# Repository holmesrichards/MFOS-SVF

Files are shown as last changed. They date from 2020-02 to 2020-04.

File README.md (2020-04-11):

# MFOS-SVF
Eurorack adaptation of the MFOS "Oldie But Goody" state variable filter

This is a Eurorack version of a state variable voltage controlled filter by Ray Wilson of musicfromouterspace.com. At that site there is a state variable VCF listed under "Analog Synthesizer Modules" but this project is based on another, earlier design listed under "Oldies But Goodies" at http://musicfromouterspace.com/index.php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.

Wilson's design was for a module in his own preferred format, with ±12V and ground soldered to the board and panel hardware mounted to the panel and wired to the board. This version has a Eurorack power connector and has panel hardware mounted to a panel PCB coupled to a main PCB with most of the circuitry.

Included in this repository are KiCad-format schematics and PCB designs for the two circuit boards, as well as an Inkscape .svg file for the panel design and a KiCad-format "PCB" for fabrication of the panel by a PCB company.

The schematics are closely based upon Wilson's original and are governed by licensing information at http://musicfromouterspace.com. The PCB layouts and panel design are new, by Richard Holmes.

BOMs are here:
https://github.com/holmesrichards/MFOS-SVF/blob/master/OBG-SVF-mainPCB/OBG-SVF-mainpcb_bom.md
and here:
https://github.com/holmesrichards/MFOS-SVF/blob/master/OBG-SVF-panelPCB/OBG-SVF-panelpcb_bom.md

## Build notes

Pretty standard. Panel PCB and main PCB joined with 2x6 pin header/socket. Use two 10 mm M3 spacers and four M3 screws to hold them together.

This time most of the components go on the panel-facing side. The power header and trimmer go on the other side. I intended the electrolytics to go on the panel-facing side but mine were too tall to fit between the boards so I mounted them on the other side.

The trimmer adjusts V/Oct response. Adjust it so a change of 1 octave (1V) on the CV input results in a change of 18 mV at the base of Q1.

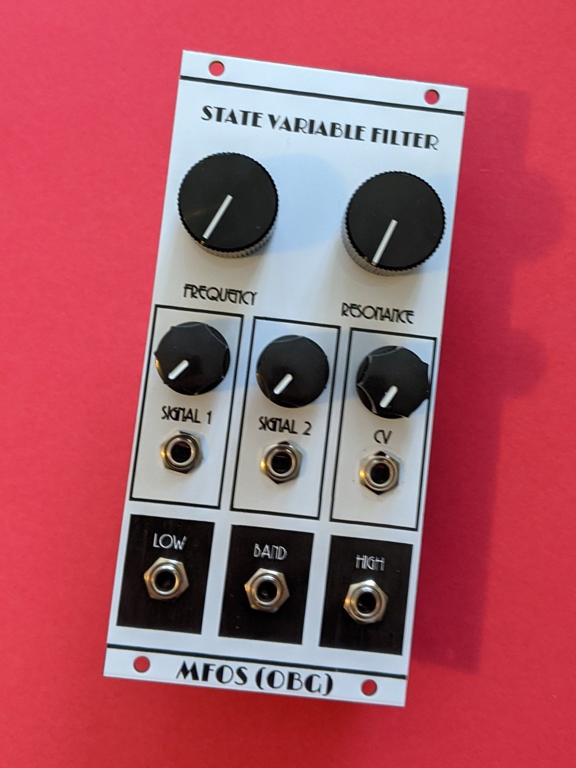
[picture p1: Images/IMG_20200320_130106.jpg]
module pic


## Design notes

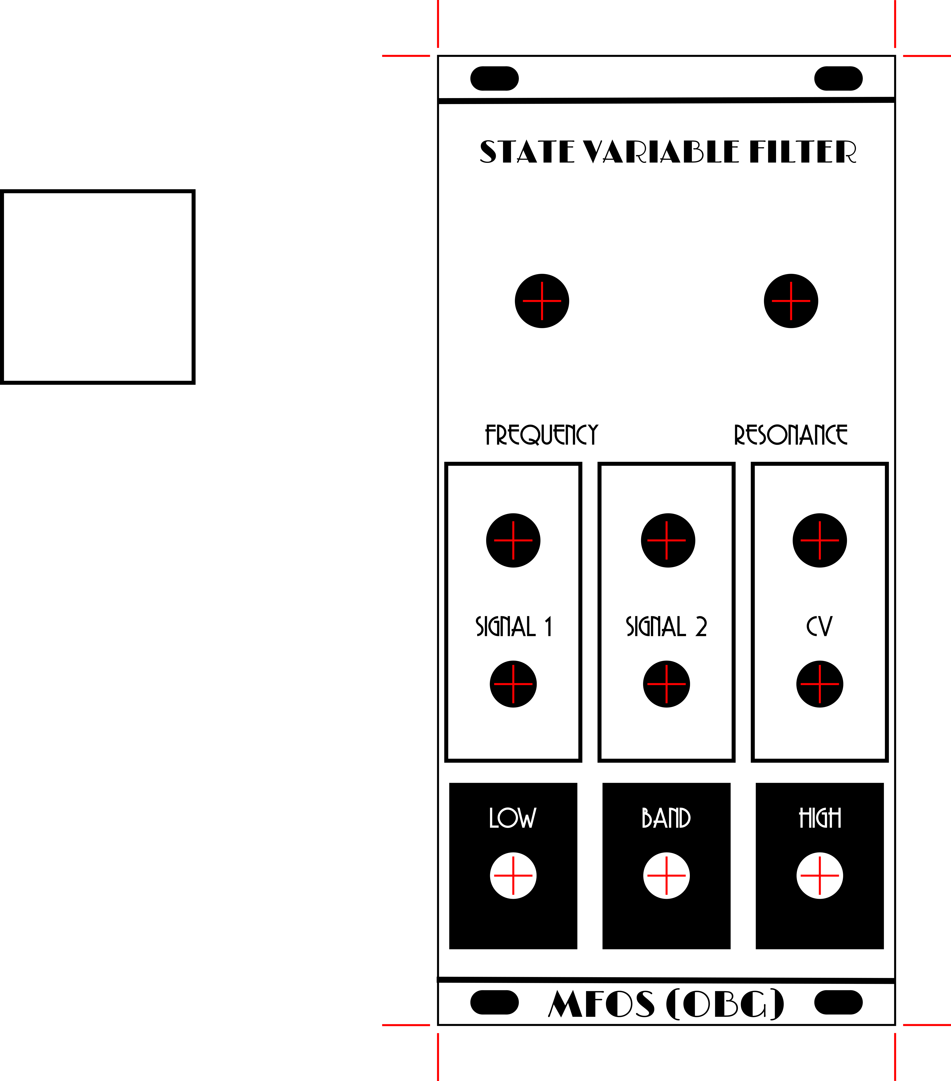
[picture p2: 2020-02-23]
OBG-SVF-panel/art labels holes.png

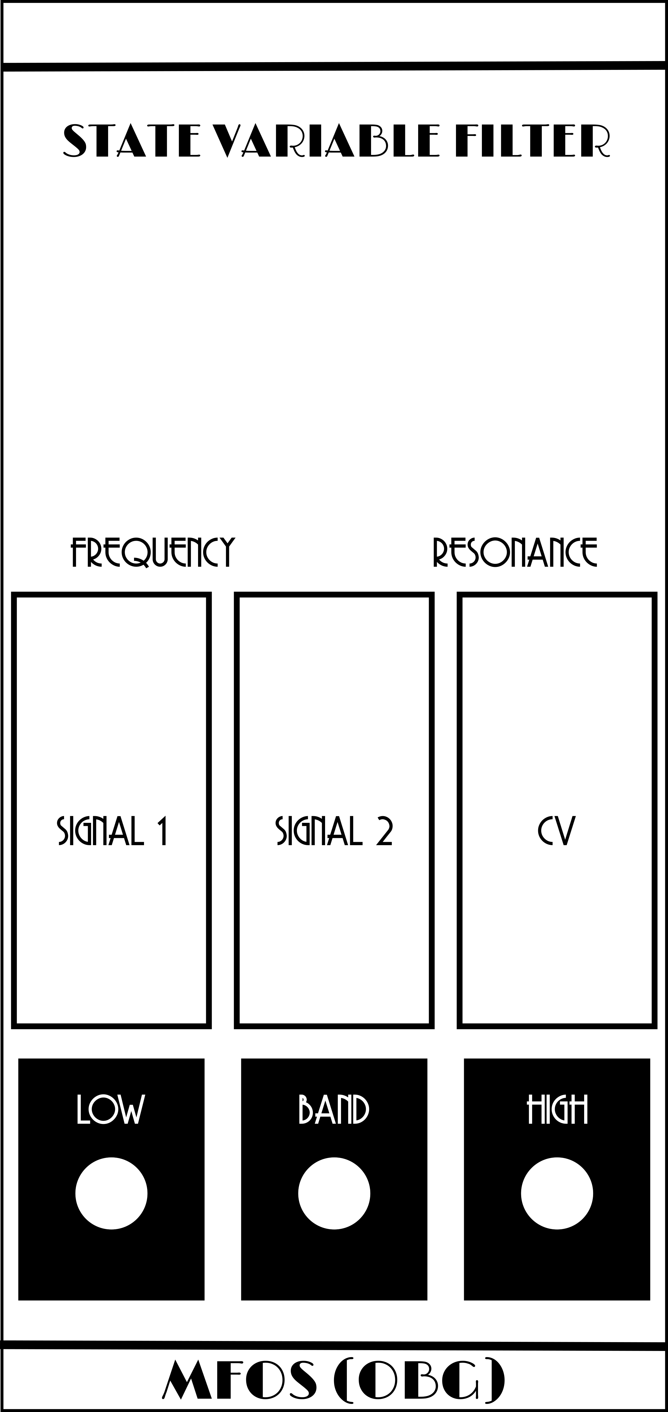
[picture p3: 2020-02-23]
OBG-SVF-panel/art labels.png

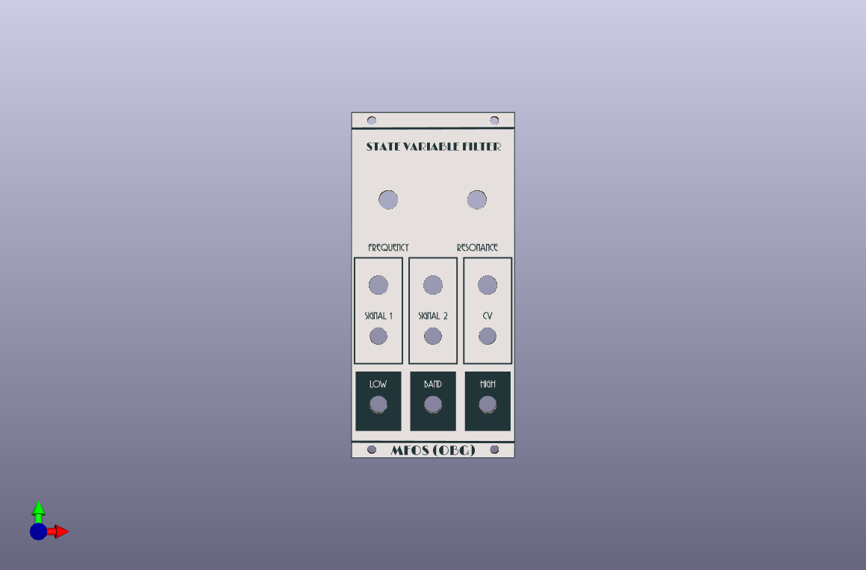
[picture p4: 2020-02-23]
OBG-SVF-panel/obg-SVF-panel.png

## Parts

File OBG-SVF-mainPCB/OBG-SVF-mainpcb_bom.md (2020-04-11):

# OBG-SVF-mainpcb BOM

Sat 11 Apr 2020 01:31:15 PM EDT

Generated from schematic by Eeschema 5.1.5-52549c5~84~ubuntu18.04.1

**Component Count:** 36

| Value | Qty | Part | Description | Vendor |
| ----- | --- | ---- | --- | --- |
| C1, C2 | 2 | 470pF | Unpolarized capacitor |  |
| C3, C4 | 2 | 10U | Polarized capacitor |  |
| C5, C6, C7, C8 | 4 | 0.1uF | Unpolarized capacitor |  |
| D1, D2 | 2 | 1N5817 | 20V 1A Schottky Barrier Rectifier Diode, DO-41 |  |
| J7 | 1 | EURO_PWR_2x5 | Eurorack style 2x5 pin power header |  |
| J8 | 1 | Conn_02x06_Odd_Even | Generic connector, double row, 02x06 |  |
| Q1 | 1 | 2N3904 | 0.2A Ic, 40V Vce, Small Signal NPN Transistor, TO-92 |  |
| Q2, Q3 | 2 | 2N3906 | -0.2A Ic, -40V Vce, Small Signal PNP Transistor, TO-92 |  |
| R3, R12 | 2 | 2k | Resistor |  |
| R4, R10, R15 | 3 | 47k | Resistor |  |
| R7 | 1 | 100R | Trim-potentiometer |  |
| R11, R17, R20 | 3 | 100k | Resistor |  |
| R13 | 1 | 470R | Resistor |  |
| R14 | 1 | 120k | Resistor |  |
| R18, R19 | 2 | 20k | Resistor |  |
| R21, R22 | 2 | 1k | Resistor |  |
| R25, R27 | 2 | 39k | Resistor |  |
| R26, R28 | 2 | 150k | Resistor |  |
| U1 | 1 | TL084 | Quad JFET-Input Operational Amplifiers, DIP-14 |  |
| U2 | 1 | LM13700 | Dual Operational Transconductance Amplifiers with Linearizing Diodes and Buffers, DIP-16 |  |

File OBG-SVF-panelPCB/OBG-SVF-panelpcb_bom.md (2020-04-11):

# OBG-SVF-panelpcb BOM

Sat 11 Apr 2020 01:33:45 PM EDT

Generated from schematic by Eeschema 5.1.5-52549c5~84~ubuntu18.04.1

**Component Count:** 20

| Value | Qty | Part | Description | Vendor |
| ----- | --- | ---- | --- | --- |
| J1, J2, J3, J4, J5, J6 | 6 | AudioJack2 |  |  |
| J9 | 1 | Conn_02x06_Odd_Even | Generic connector, double row, 02x06, odd/even pin numbering scheme (row 1 odd numbers, row 2 even numbers), script generated (kicad-library-utils/schlib/autogen/connector/) |  |
| R1, R5, R31, R32, R33 | 5 | 100k | Potentiometer |  |
| R2, R6 | 2 | 100k | Resistor |  |
| R8 | 1 | 9.1k | Resistor |  |
| R9, R29 | 2 | 270k | Resistor |  |
| R16, R23, R24 | 3 | 1k | Resistor |  |
    
*Additional parts not on schematic:*

| Qty | Part | Description |
| --- | ---- | --- |
| 2 | 10 mm x M3 | Spacer |
| 4 | M3 | Screw |
| 5 | | Knob |

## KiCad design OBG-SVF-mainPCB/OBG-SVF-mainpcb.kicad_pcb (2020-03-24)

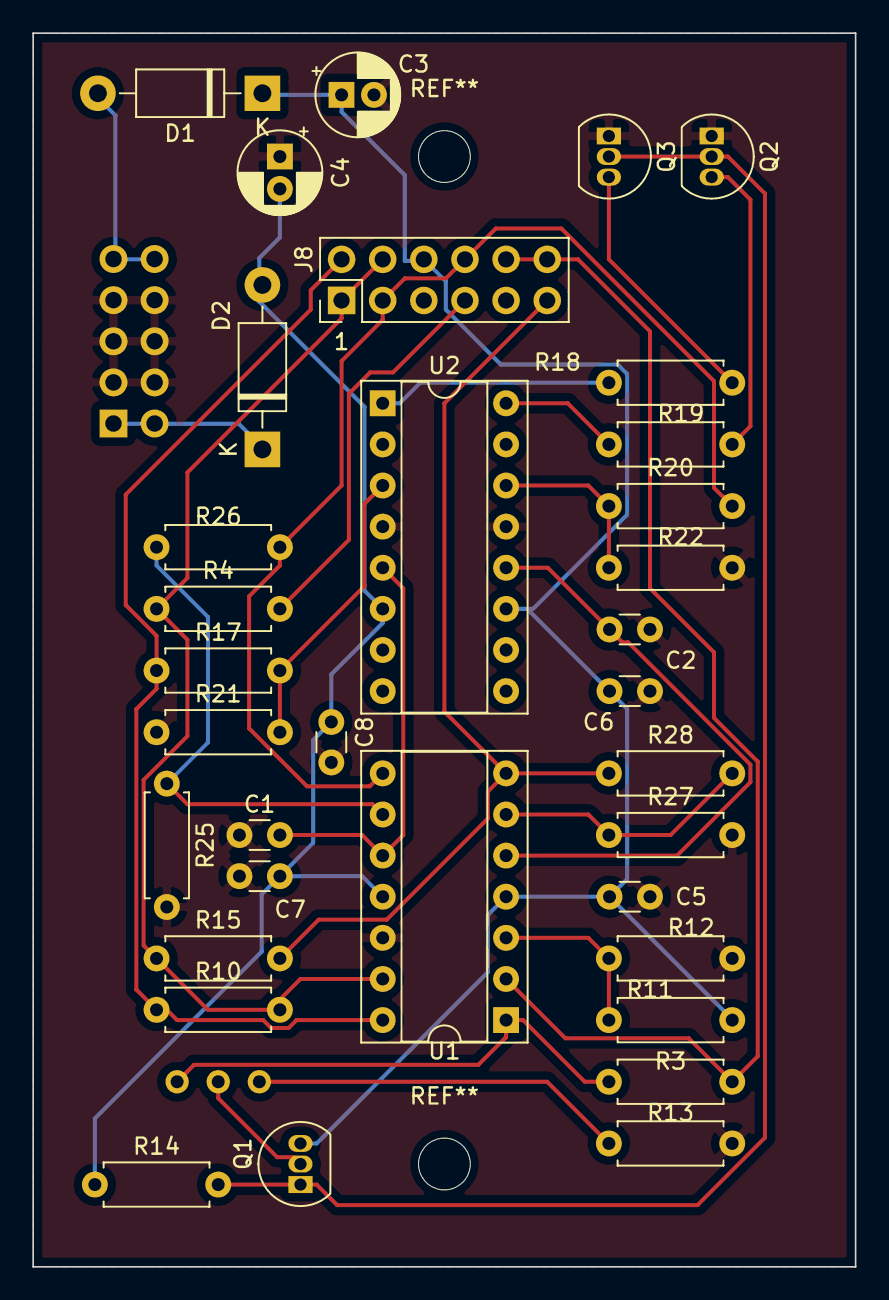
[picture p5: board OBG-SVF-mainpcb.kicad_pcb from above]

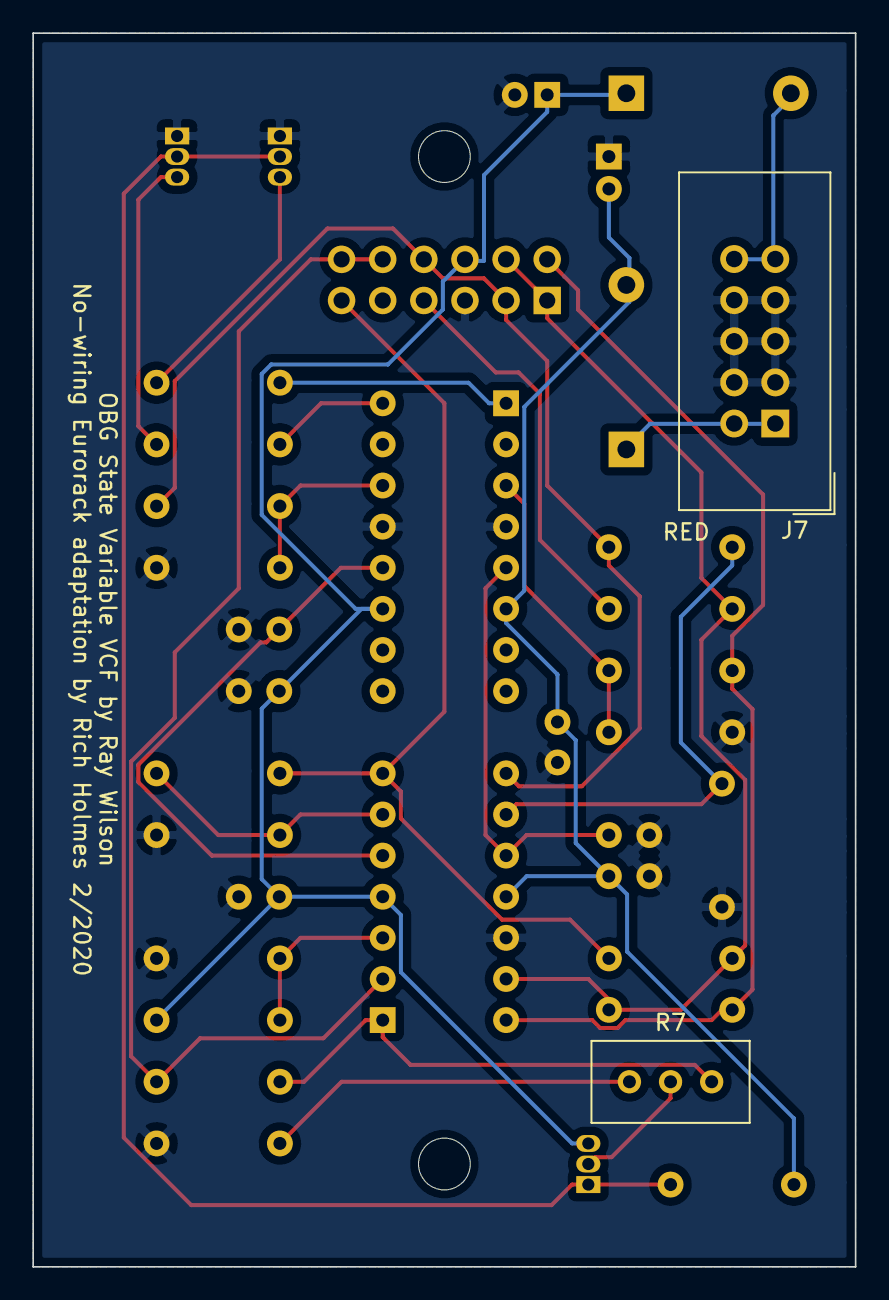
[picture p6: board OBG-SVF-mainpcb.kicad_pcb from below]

Board: 2 copper layers, 50.8 x 76.2 mm, 36 parts (2 on the bottom side), 26 nets.

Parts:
C1, C2: 470pF; C_Disc_D3.0mm_W1.6mm_P2.50mm
C3, C4: 10U; CP_Radial_D5.0mm_P2.00mm
C5, C6, C7, C8: 0.01U; C_Disc_D3.0mm_W1.6mm_P2.50mm
D1, D2: 1N5817; D_DO-41_SOD81_P10.16mm_Horizontal
J7: EURO_PWR_2x5; Eurorack_Power_Header_Shrouded
J8: Conn_02x06_Odd_Even; PinHeader_2x06_P2.54mm_Vertical
Q1: 2N3904; TO-92_Inline
Q2, Q3: 2N3906; TO-92_Inline
R3, R12: 2k; R_Axial_DIN0207_L6.3mm_D2.5mm_P7.62mm_Horizontal
R4, R10, R15: 47k; R_Axial_DIN0207_L6.3mm_D2.5mm_P7.62mm_Horizontal
R7: 100R; Potentiometer_Bourns_3296W_Vertical
R11, R17, R20: 100k; R_Axial_DIN0207_L6.3mm_D2.5mm_P7.62mm_Horizontal
R13: 470R; R_Axial_DIN0207_L6.3mm_D2.5mm_P7.62mm_Horizontal
R14: 120k; R_Axial_DIN0207_L6.3mm_D2.5mm_P7.62mm_Horizontal
R18, R19: 20k; R_Axial_DIN0207_L6.3mm_D2.5mm_P7.62mm_Horizontal
R21, R22: 1k; R_Axial_DIN0207_L6.3mm_D2.5mm_P7.62mm_Horizontal
R25, R27: 39k; R_Axial_DIN0207_L6.3mm_D2.5mm_P7.62mm_Horizontal
R26, R28: 150k; R_Axial_DIN0207_L6.3mm_D2.5mm_P7.62mm_Horizontal
U1: TL084; DIP-14_W7.62mm_Socket
U2: LM13700; DIP-16_W7.62mm_Socket

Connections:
+12V: C3.1, C5.2, C6.2, D1.1, J8.6, Q1.3, R11.2, U1.4, U2.11
-12V: C4.2, C7.1, C8.1, D2.2, R14.1, U1.11, U2.6
/VC: Q1.1, Q2.2, Q3.2, R14.2
BP: J8.3, J8.8, R20.2, R26.1, U1.8
CVIn: J8.10, J8.12, R3.2, U1.2
GND: C1.2, C2.1, C3.2, C4.1, C5.1, C6.1, C7.2, C8.2, J7.3, J7.4, J7.5, J7.6, J7.7, J7.8, J8.5, Q2.1, Q3.1, R12.1, R13.1, R21.1, R22.1, R25.2, R27.2, U1.12, U2.4, U2.13
HP: J8.2, R10.1, R17.1, U1.14
LP: J8.11, R15.2, R28.1, U1.7
unnamed: C1.1, U1.10, U2.5
unnamed: C2.2, U1.5, U2.12
unnamed: D1.2, J7.9, J7.10
unnamed: D2.1, J7.1, J7.2
unnamed: Q1.2, R7.2
unnamed: Q2.3, R19.1
unnamed: Q3.3, R18.1
unnamed: R3.1, R7.1, U1.1
unnamed: R11.1, R12.2, U1.3
unnamed: R7.3, R13.2
unnamed: R17.2, R21.2, U2.3
unnamed: R18.2, U2.1
unnamed: R19.2, U2.16
unnamed: R20.1, R22.2, U2.14
unnamed: R25.1, R26.2, U1.9
unnamed: R27.1, R28.2, U1.6
Res1: J8.7, R4.2
SigIn: J8.1, J8.4, R4.1, R10.2, R15.1, U1.13

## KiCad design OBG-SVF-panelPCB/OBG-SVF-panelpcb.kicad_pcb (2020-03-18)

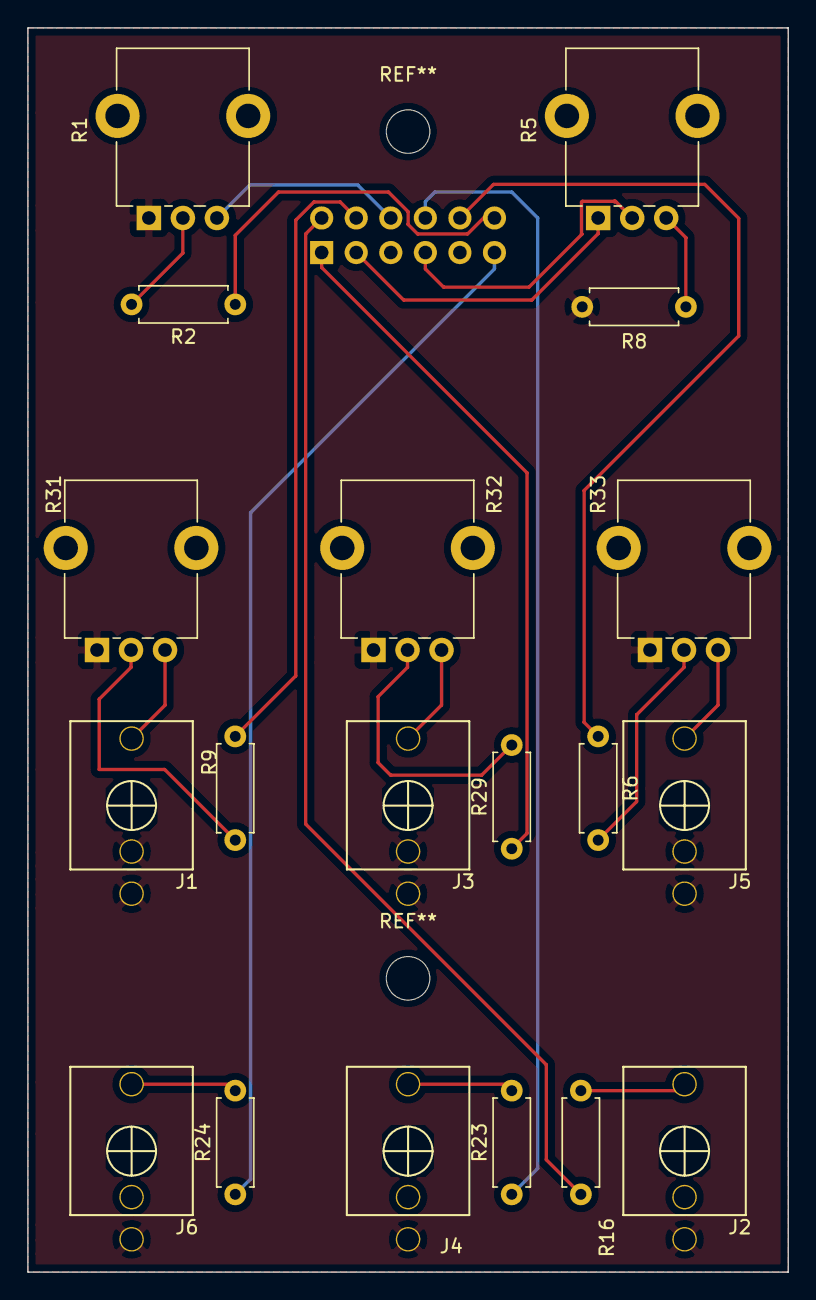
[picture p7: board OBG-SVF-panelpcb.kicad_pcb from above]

Board: 2 copper layers, 55.9 x 91.4 mm, 20 parts (1 on the bottom side), 22 nets.

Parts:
J1, J2, J3, J4, J5, J6: AudioJack2; PJ301M-12
J9: Conn_02x06_Odd_Even; PinSocket_2x06_P2.54mm_Vertical
R1, R5, R31, R32, R33: 100k; Potentiometer_Alpha_RD901F-40-00D_Single_Vertical_CircularH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
R2, R6: 100k; R_Axial_DIN0207_L6.3mm_D2.5mm_P7.62mm_Horizontal
R8: 9.1k; R_Axial_DIN0207_L6.3mm_D2.5mm_P7.62mm_Horizontal
R9, R29: 270k; R_Axial_DIN0207_L6.3mm_D2.5mm_P7.62mm_Horizontal
R16, R23, R24: 1k; R_Axial_DIN0207_L6.3mm_D2.5mm_P7.62mm_Horizontal

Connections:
+12V: J9.6, R1.3
BP: J9.8, R23.1
CVIn: J9.10, R6.1
GND: J1.1, J1.2, J2.1, J3.1, J3.2, J4.1, J5.1, J5.2, J6.1, J9.5, R1.1, R8.1, R31.1, R32.1, R33.1
HP: J9.2, R16.2
LP: J9.11, R24.1
unnamed: J1.3, R31.3
unnamed: J2.3, R16.1
unnamed: J3.3, R32.3
unnamed: J4.3, R23.2
unnamed: J5.3, R33.3
unnamed: J6.3, R24.2
unnamed: R1.2, R2.2
unnamed: R5.3, R8.2
unnamed: R29.2, R32.2
unnamed: R9.2, R31.2
unnamed: R6.2, R33.2
R1(2): J9.12, R2.1
Res1: J9.7, R5.2
Res2: J9.3, R5.1
SigIn: J9.4, R9.1
SigIn2: J9.1, R29.1

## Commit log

2020-02-23 Initial version
    [OBG-SVF-mainpcb.kicad_pcb, OBG-SVF-mainpcb.sch, OBG-SVF-panelpcb.kicad_pcb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]
2020-03-18 Panel PCB Gerbers, some schematic updates
    [OBG-SVF-mainpcb.kicad_pcb, OBG-SVF-mainpcb.sch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]
2020-03-18 main PCB and panel Gerbers
    [OBG-SVF-mainpcb-B_Cu.gbr, OBG-SVF-mainpcb-B_Mask.gbr, OBG-SVF-mainpcb-B_Paste.gbr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]
2020-03-24 Fix bypass capacitors
    [OBG-SVF-mainpcb.kicad_pcb, OBG-SVF-mainpcb.sch]
2020-04-11 BOM links
2020-04-12 Move global library to local
    [OBG-SVF-mainpcb.sch, OBG-SVF-panelpcb.sch]
2020-09-01 Belated commit of various updates
    [obg-SVF-panel.sch]
